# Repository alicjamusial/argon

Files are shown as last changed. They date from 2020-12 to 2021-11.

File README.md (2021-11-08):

# Argon & Benzene - SPI NOR Flash programmer & reader

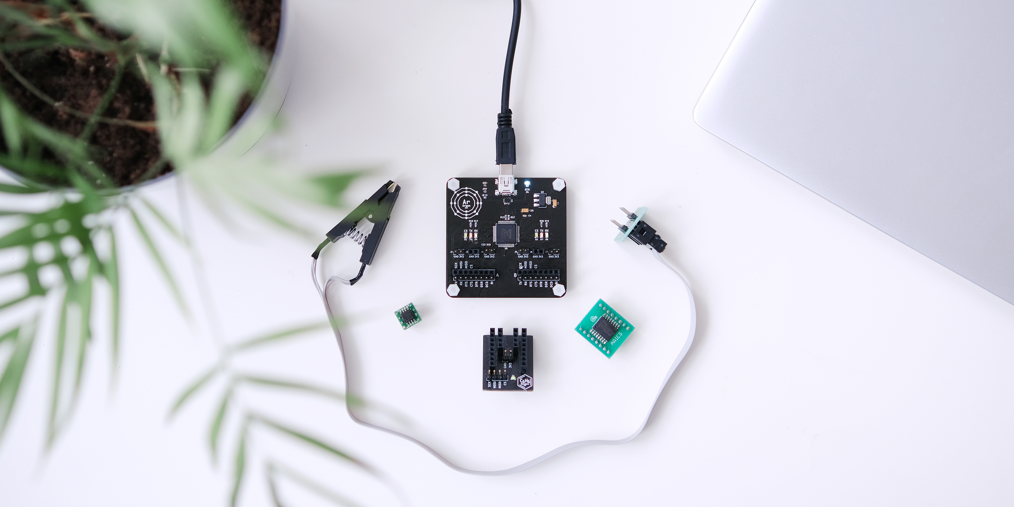
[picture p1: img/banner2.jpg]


### ◾ About the project

This project consists of two boards: **Argon** and **Benzene**.

 **Argon** is a SPI NOR flash programmer & reader. It's based on the FT2232H microcontroller (with two UARTs - A & B). The board has three LED indicators of data - on TX, RX and CS lines and some sockets to be able to plug in the logic analyzer. Version 1.0 of Argon is available [in the releases section](https://github.com/alicjamusial/argon/releases/tag/argon-1.0). 

<br>

 **Benzene** is a DIP-8/DIP-16 to Argon adapter. It includes mostly a few capacitors and resistors to allow SPI flash to run smoothly. There is also a 555 timer with LED indicator on CS line goldpins to attach the logic analyzer.
Version 1.0 of Benzene is available [in the releases section](https://github.com/alicjamusial/argon/releases/tag/benzene-1.0).

<br>
Argon works best with Benzene attached - they are designed to match each other (you can put two Benzene boards on top of the Argon). Argon can be also used separately as USB<->UART/FIFO/I2C/SPI converter (similar to FTDI Mini Module). 

Both boards were designed using [KiCad 5.1.6](https://kicad.org/).

### ◾ Software
Argon software is available in [this repository](https://github.com/alicjamusial/argon-driver).

### ◾ Known issues
**Argon 1.1**
- No known issues, but wasn't assembled yet.

**Benzene 1.0**
- Logo is too small and illegible (not very important, so won't be fixed by now)

**Project**
- KiCad libraries are a bit chaotic (not very important, so won't be fixed by now)

### ◾ Usage examples
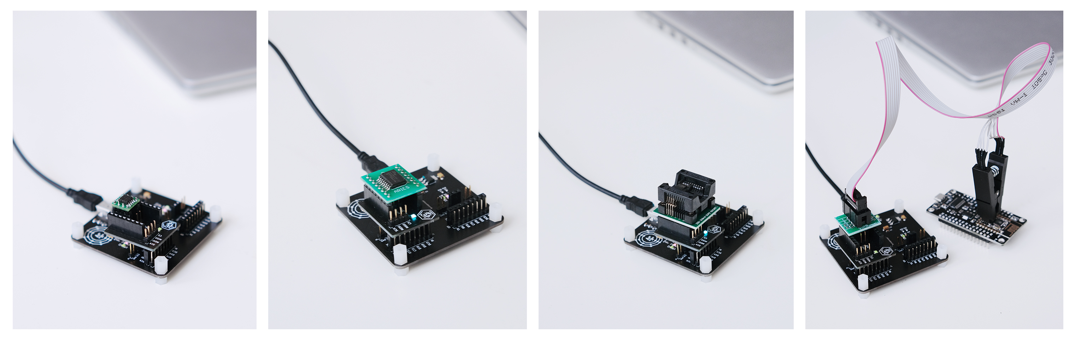
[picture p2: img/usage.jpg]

Argon is meant to be used as SPI NOR flash reader & writer with:
- Benzene & flash soldered to DIP-8/DIP-16 board adapter
- Benzene & flash inside DIP-8/DIP-16 adapter
- Benzene & clip with DIP-8/16 adapter to read or program flash placed on another board

It can be also used standalone as USB<->UART/FIFO/I2C/SPI converter (all FTDI Mini Module functionalities in the nicer and more readable form).

Note: all photos show Argon in version 1.0.

### ◾ Schematics and designs
All of them can be found [in the releases section](https://github.com/alicjamusial/argon/releases) as KiCad files, gerber files, pdf and svg format.

#### ▪️ Argon 1.1
schema
board
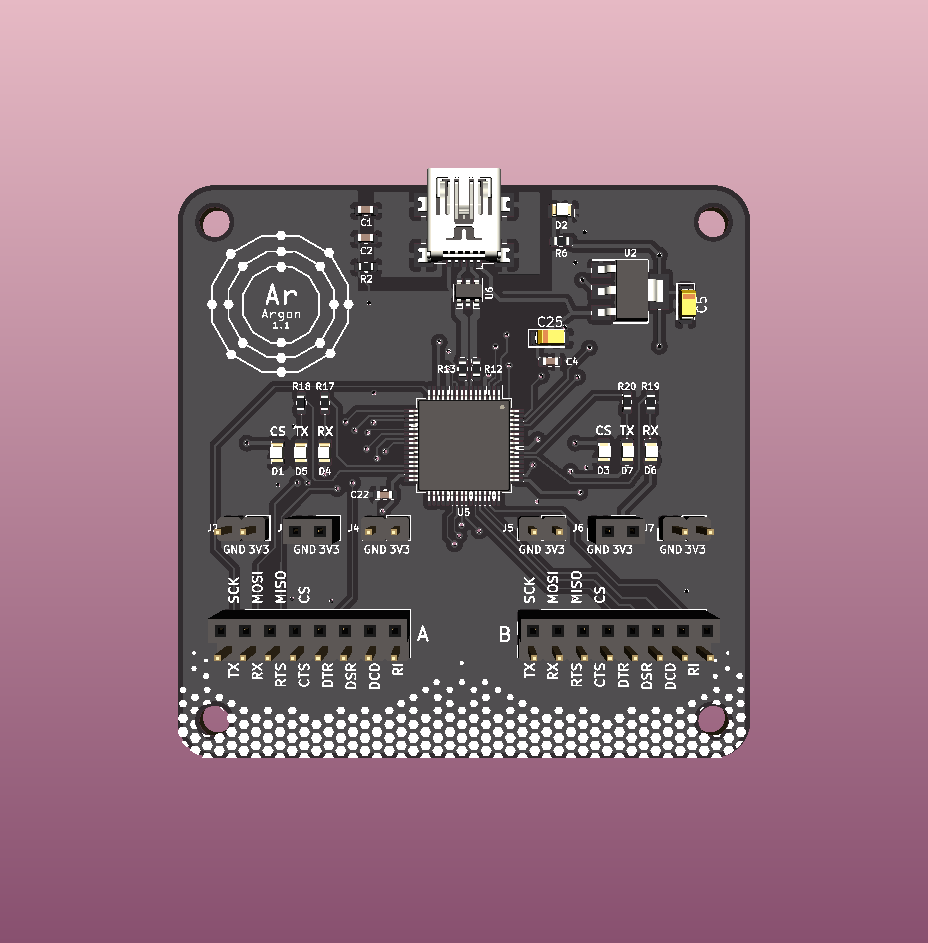
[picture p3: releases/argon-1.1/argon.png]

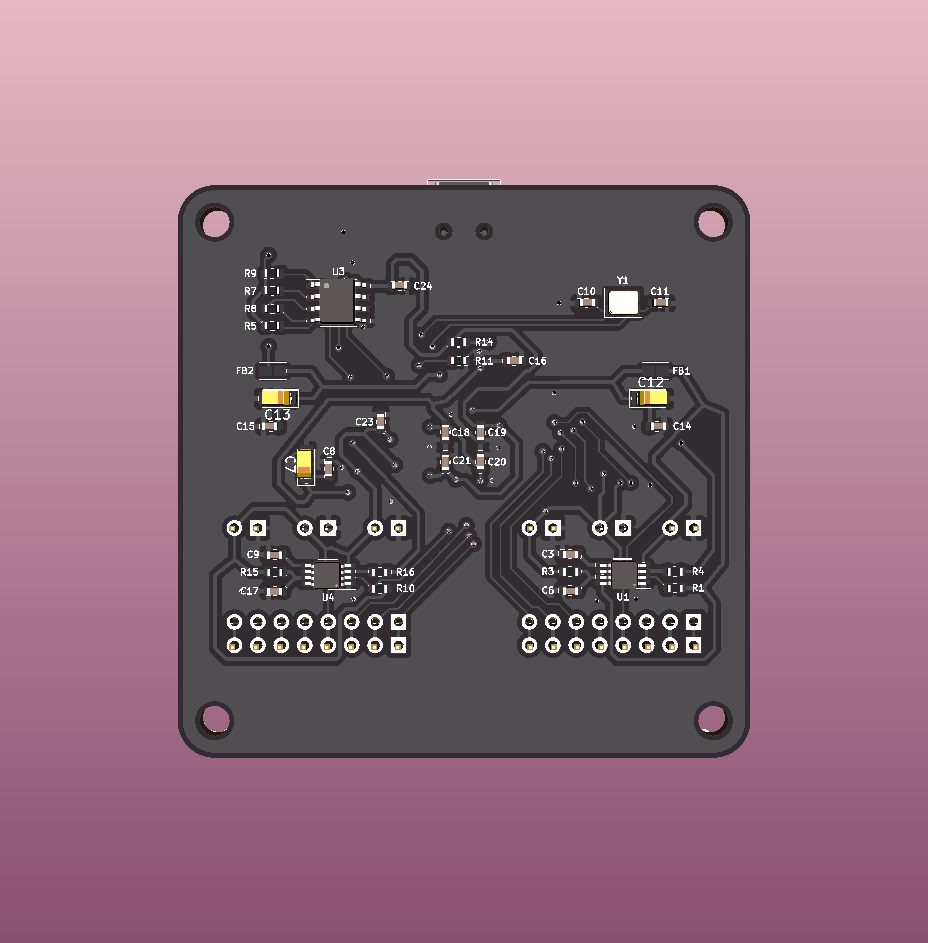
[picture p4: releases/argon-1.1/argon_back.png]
3d_back

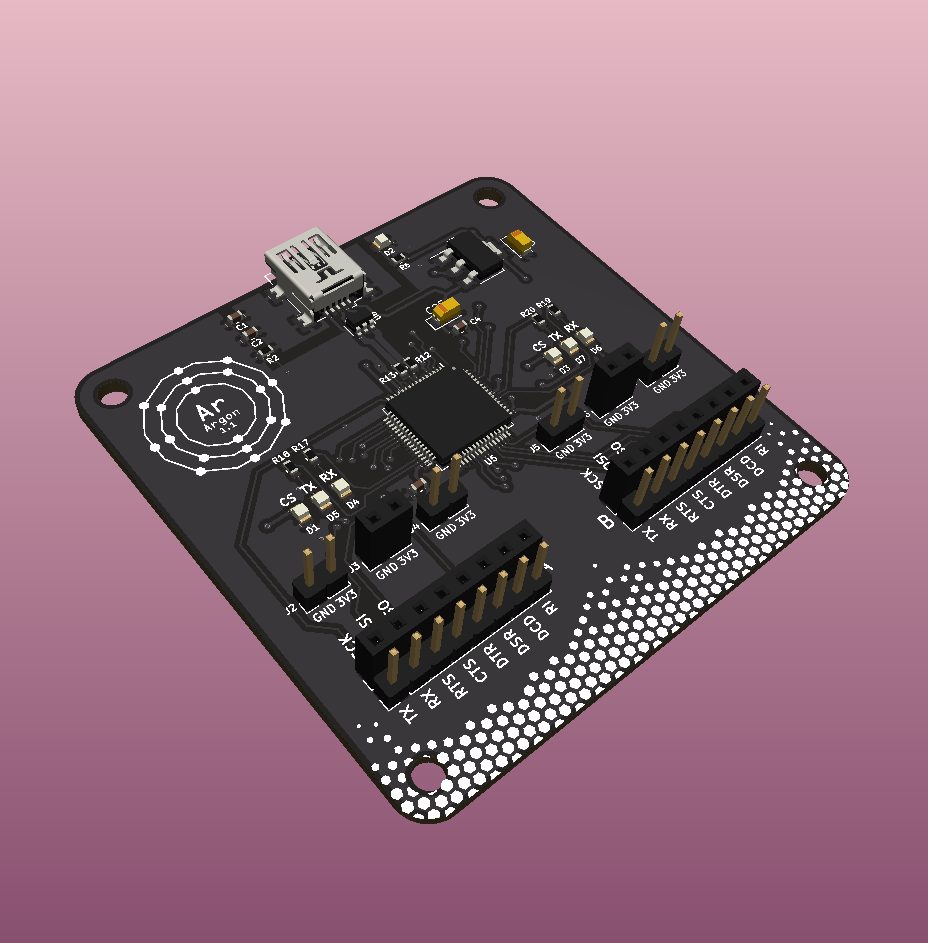
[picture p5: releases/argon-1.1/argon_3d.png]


#### ▪️ Benzene 1.0
schema
board
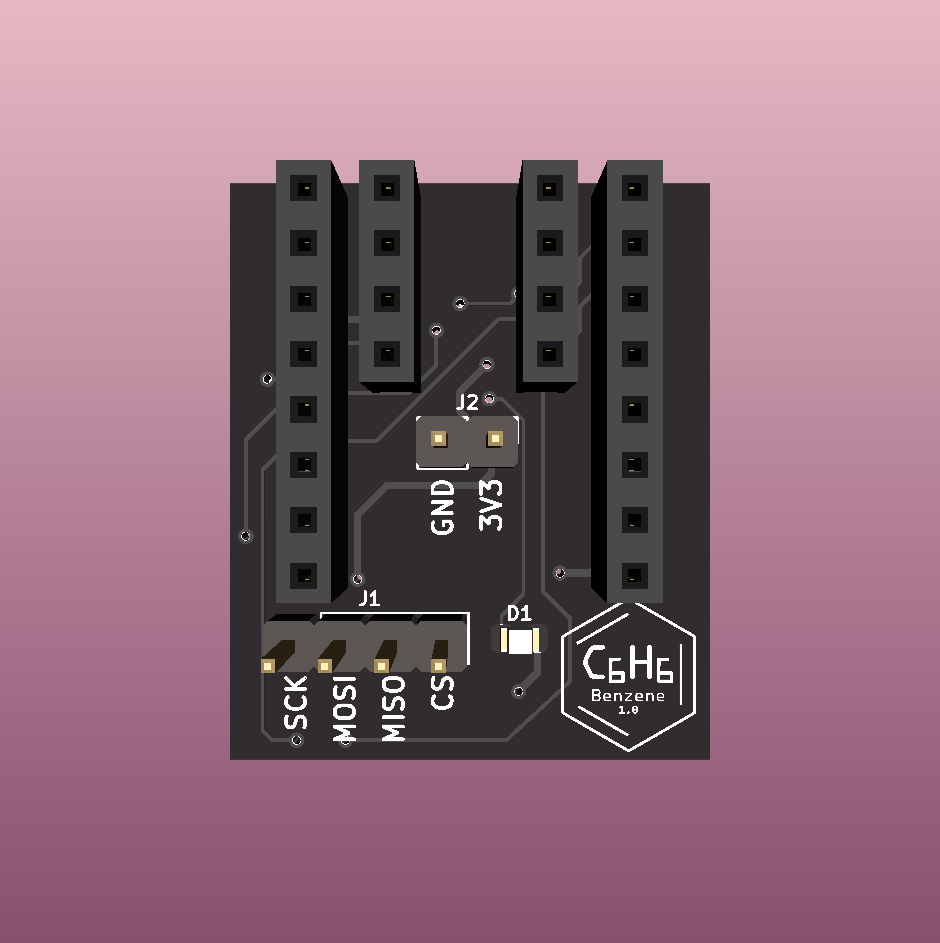
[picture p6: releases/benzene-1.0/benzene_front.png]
3d_front

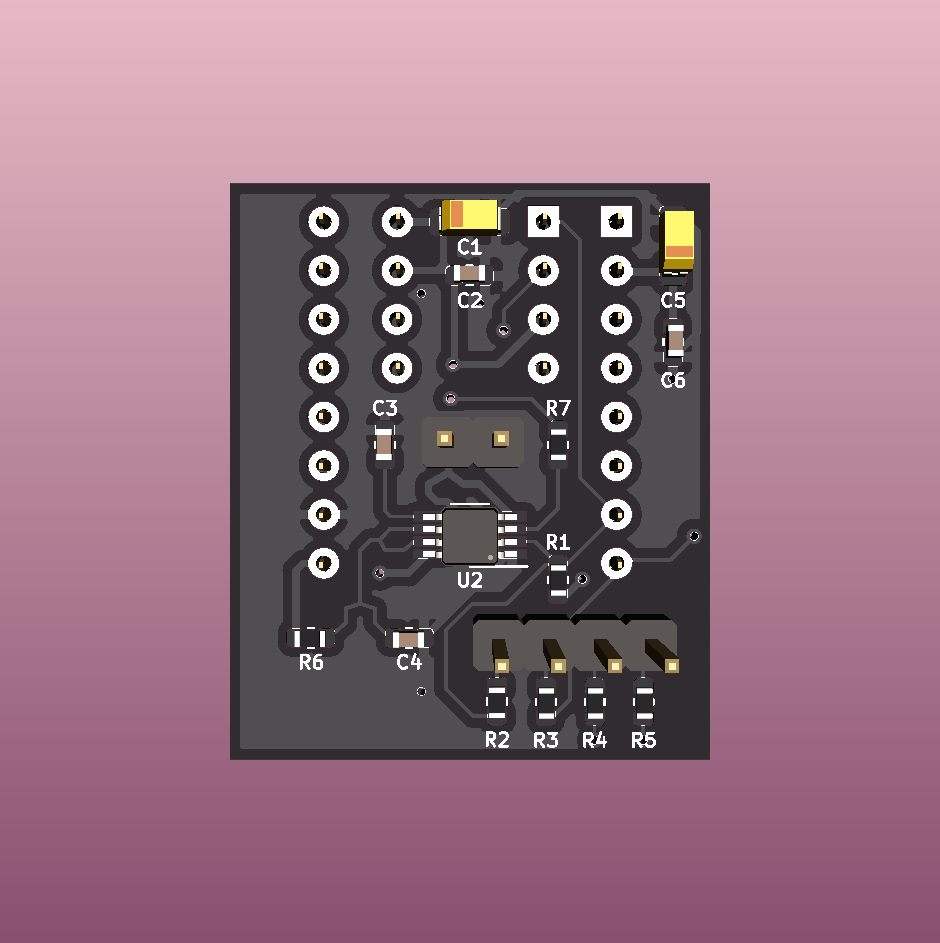
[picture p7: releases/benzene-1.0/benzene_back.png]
3d_back

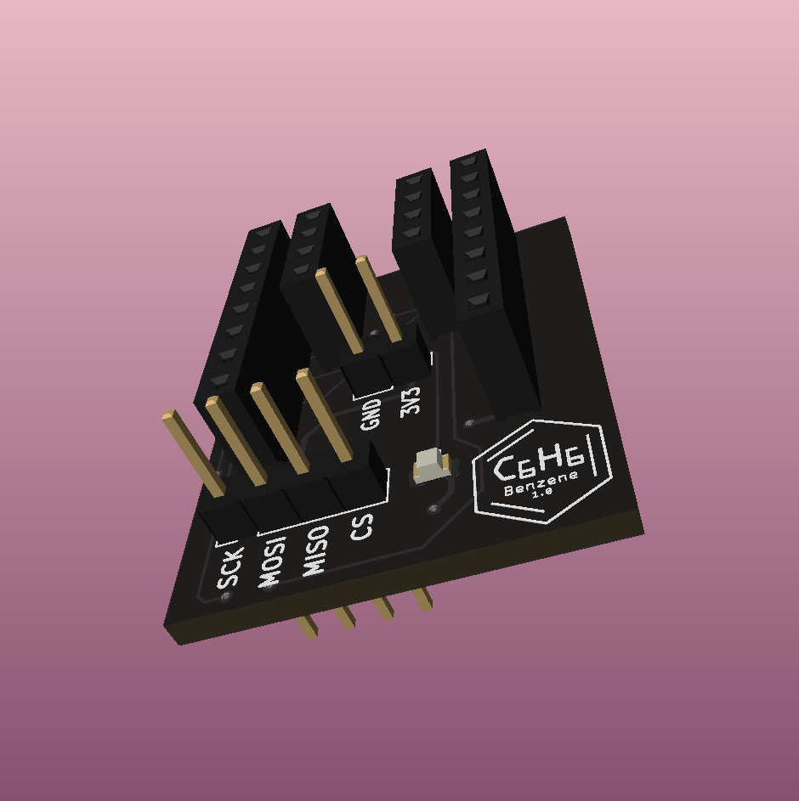
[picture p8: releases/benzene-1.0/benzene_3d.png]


### ◾ Other hints
When assembling your own Argon or Benzene please use LED's resistors calculated for your chosen colours.

### ◾ License
Argon and Benzene are available on Creative Commons Attribution Share Alike 4.0 International license (more in [license file](LICENSE.txt)). You are free to use it, modify it and produce as many of your own boards as you need :)

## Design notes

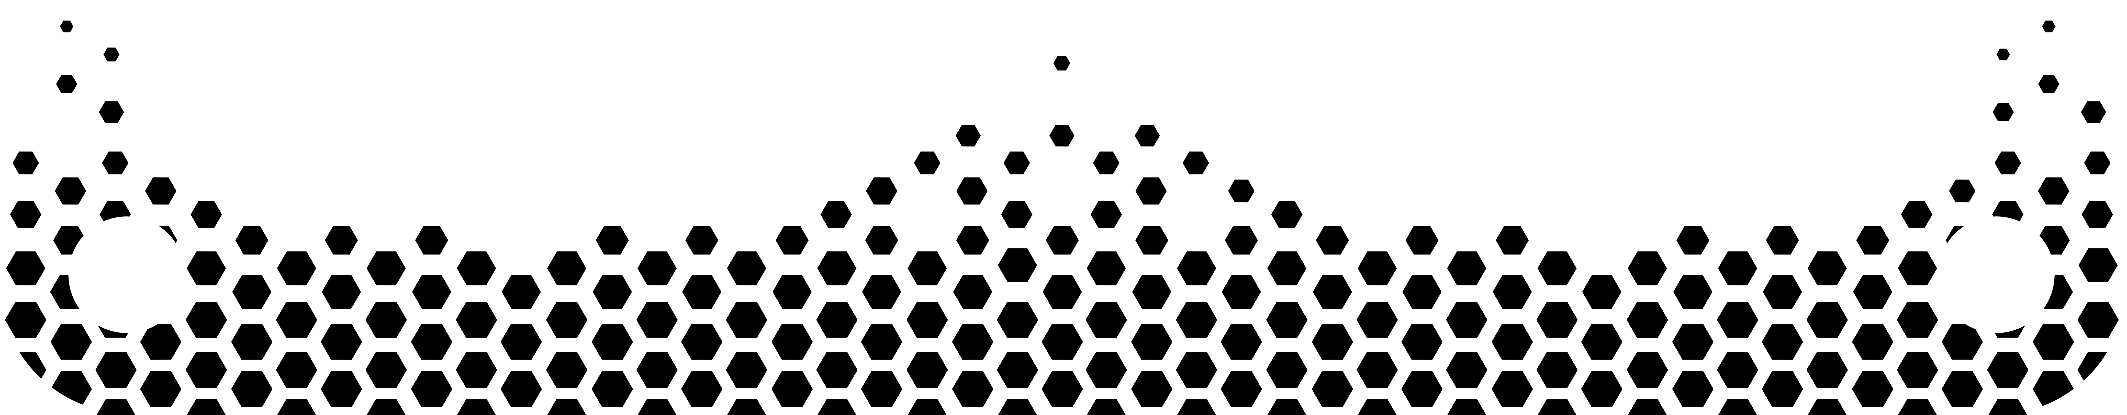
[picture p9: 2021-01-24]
img/pattern_argon.png

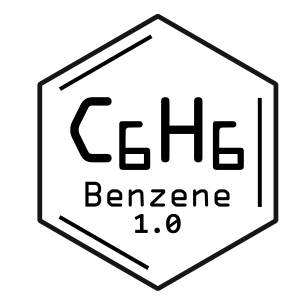
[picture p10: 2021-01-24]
benzene/benzene2.png

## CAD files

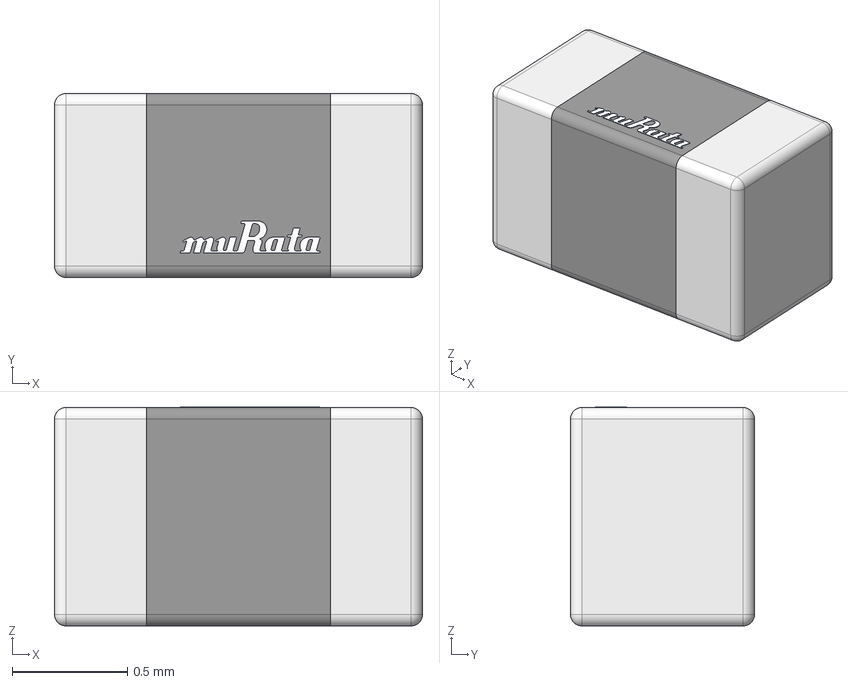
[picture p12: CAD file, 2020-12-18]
argon-libs/FBead_Murata_BLM18AG601SN1D/eec.models/Murata_-_BLM18AG601SN1D.step
1.60 x 0.8 x 0.952 mm
side x 2
Murata_

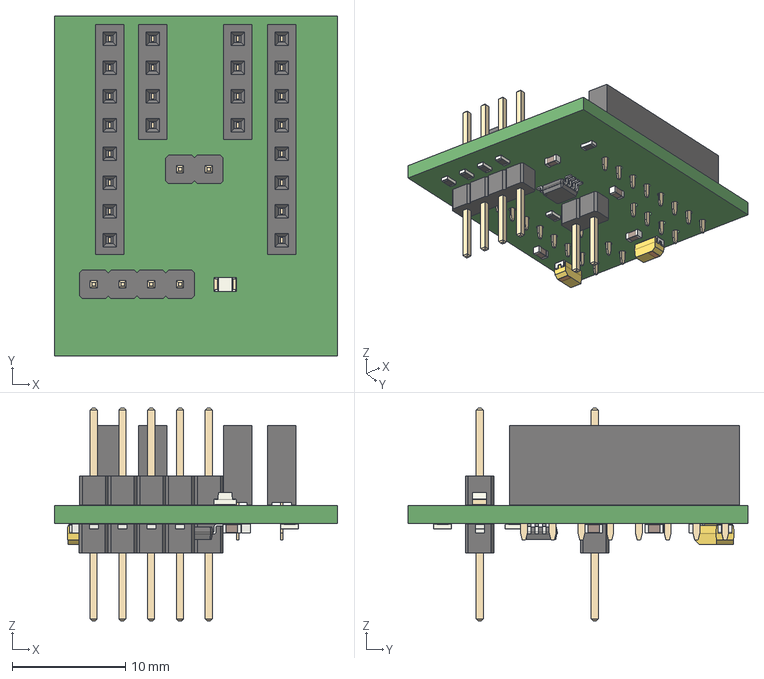
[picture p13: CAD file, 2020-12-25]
benzene/benzene.step
25.0 x 30.0 x 18.8 mm

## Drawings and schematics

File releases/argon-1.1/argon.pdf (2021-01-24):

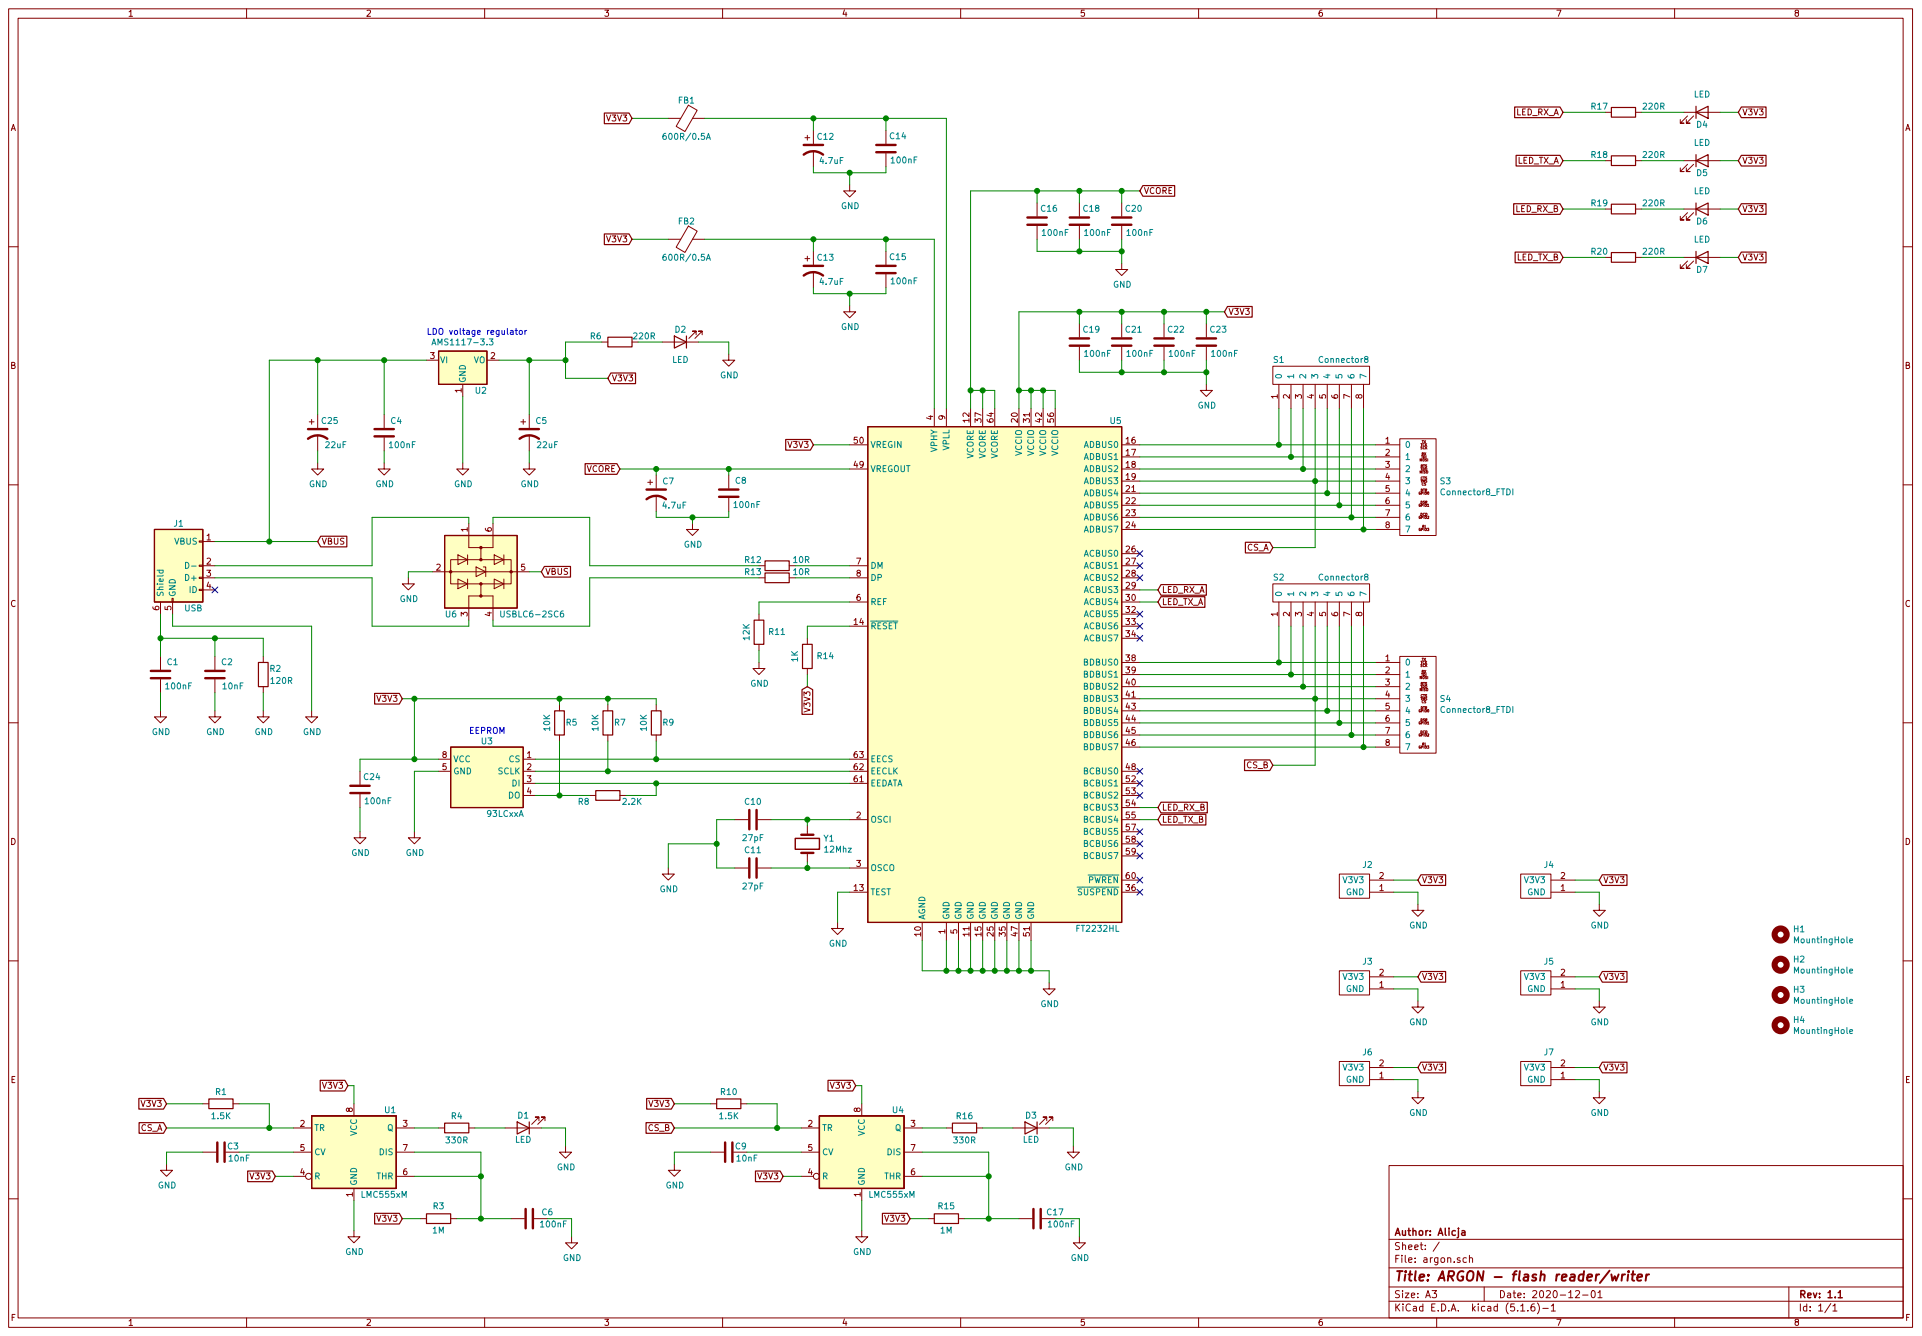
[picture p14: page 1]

1 AGND 10 GND 11 VCORE 12 TEST 13 RESET 14 GND 15 ADBUS0 16 ADBUS1 17 ADBUS2 18 ADBUS3 19 OSCI 2 VCCIO 20 ADBUS4 21 ADBUS5 22 ADBUS6 23 ADBUS7 24 GND 25 ACBUS0 26 ACBUS1 27 ACBUS2 28 ACBUS3 29 OSCO 3 ACBUS4 30 VCCIO 31 ACBUS5 32 ACBUS6 33 ACBUS7 34 GND 35 SUSPEND 36 VCORE 37 BDBUS0 38 BDBUS1 39 VPHY

4 BDBUS2 40 BDBUS3 41 VCCIO 42 BDBUS4 43 BDBUS5 44 BDBUS6 45 BDBUS7 46 GND 47 BCBUS0 48 VREGOUT 49 GND

5 VREGIN 50 GND 51 BCBUS1 52 BCBUS2 53 BCBUS3 54 BCBUS4 55 VCCIO 56 BCBUS5 57 BCBUS6 58 BCBUS7 59 REF 6 PWREN 60 EEDATA 61 EECLK 62 EECS 63 VCORE 64 DM 7 DP 8 VPLL

File: argon.sch Sheet: / Author: Alicja

Id: 1/1 Title: ARGON - flash reader/writer

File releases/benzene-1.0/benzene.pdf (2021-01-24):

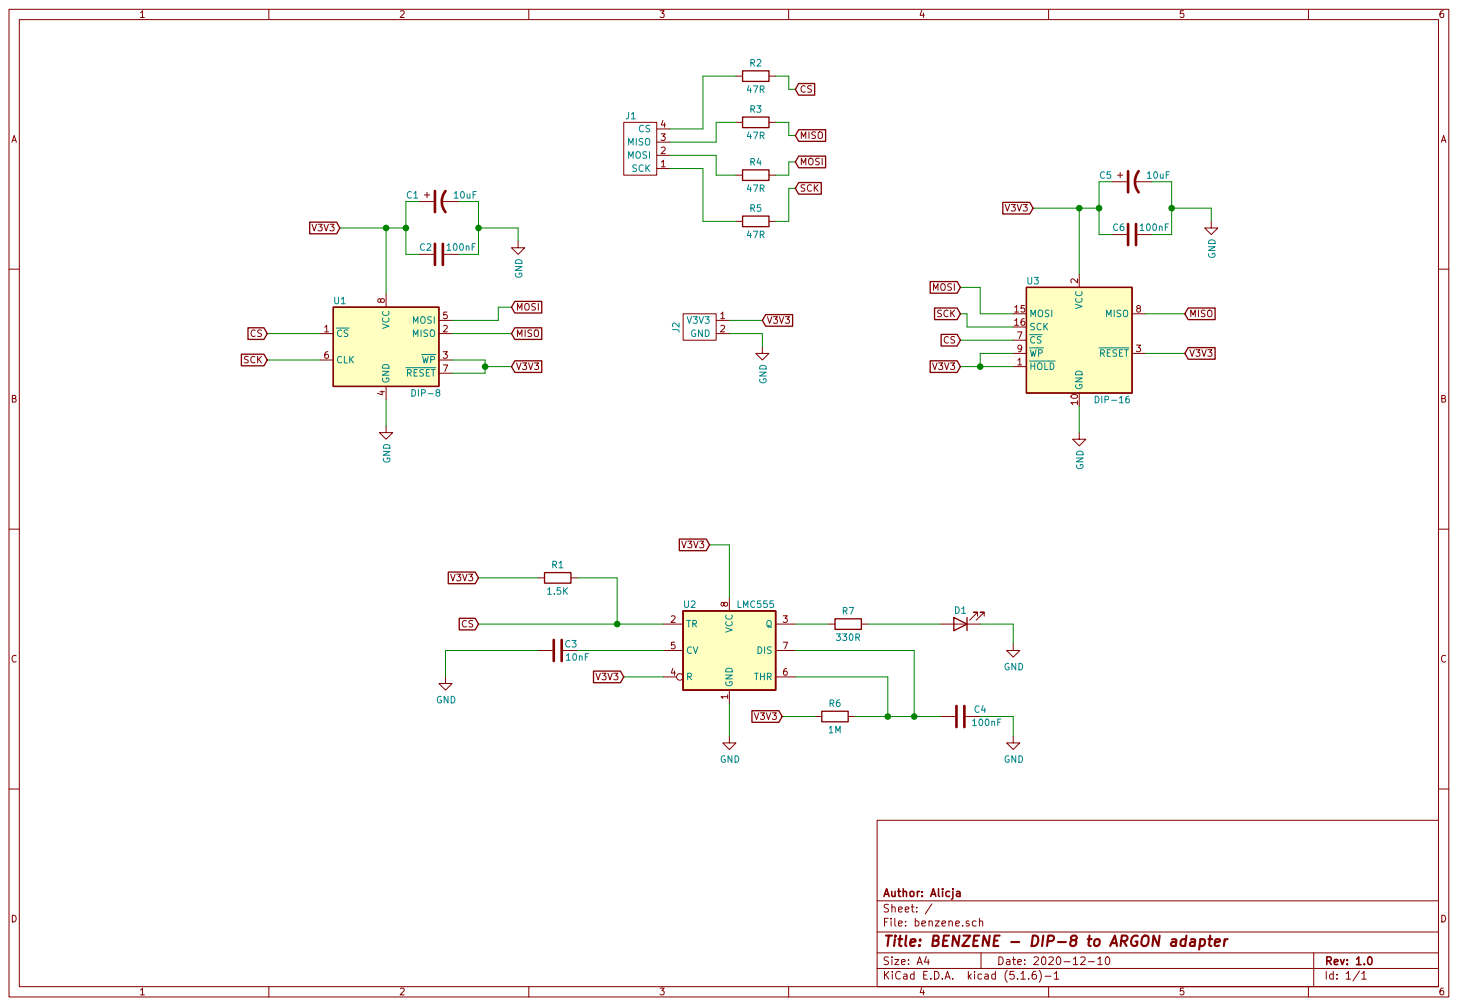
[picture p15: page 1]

2 RESET 3 CS 7 MISO 8 WP 9 U3 DIP-16 V3V3 1 GND J22 GND

4 MOSI 5 CLK 6 RESET 7 VCC

Id: 1/1 Title: BENZENE - DIP-8 to ARGON adapter File: benzene.sch Sheet: / Author: Alicja

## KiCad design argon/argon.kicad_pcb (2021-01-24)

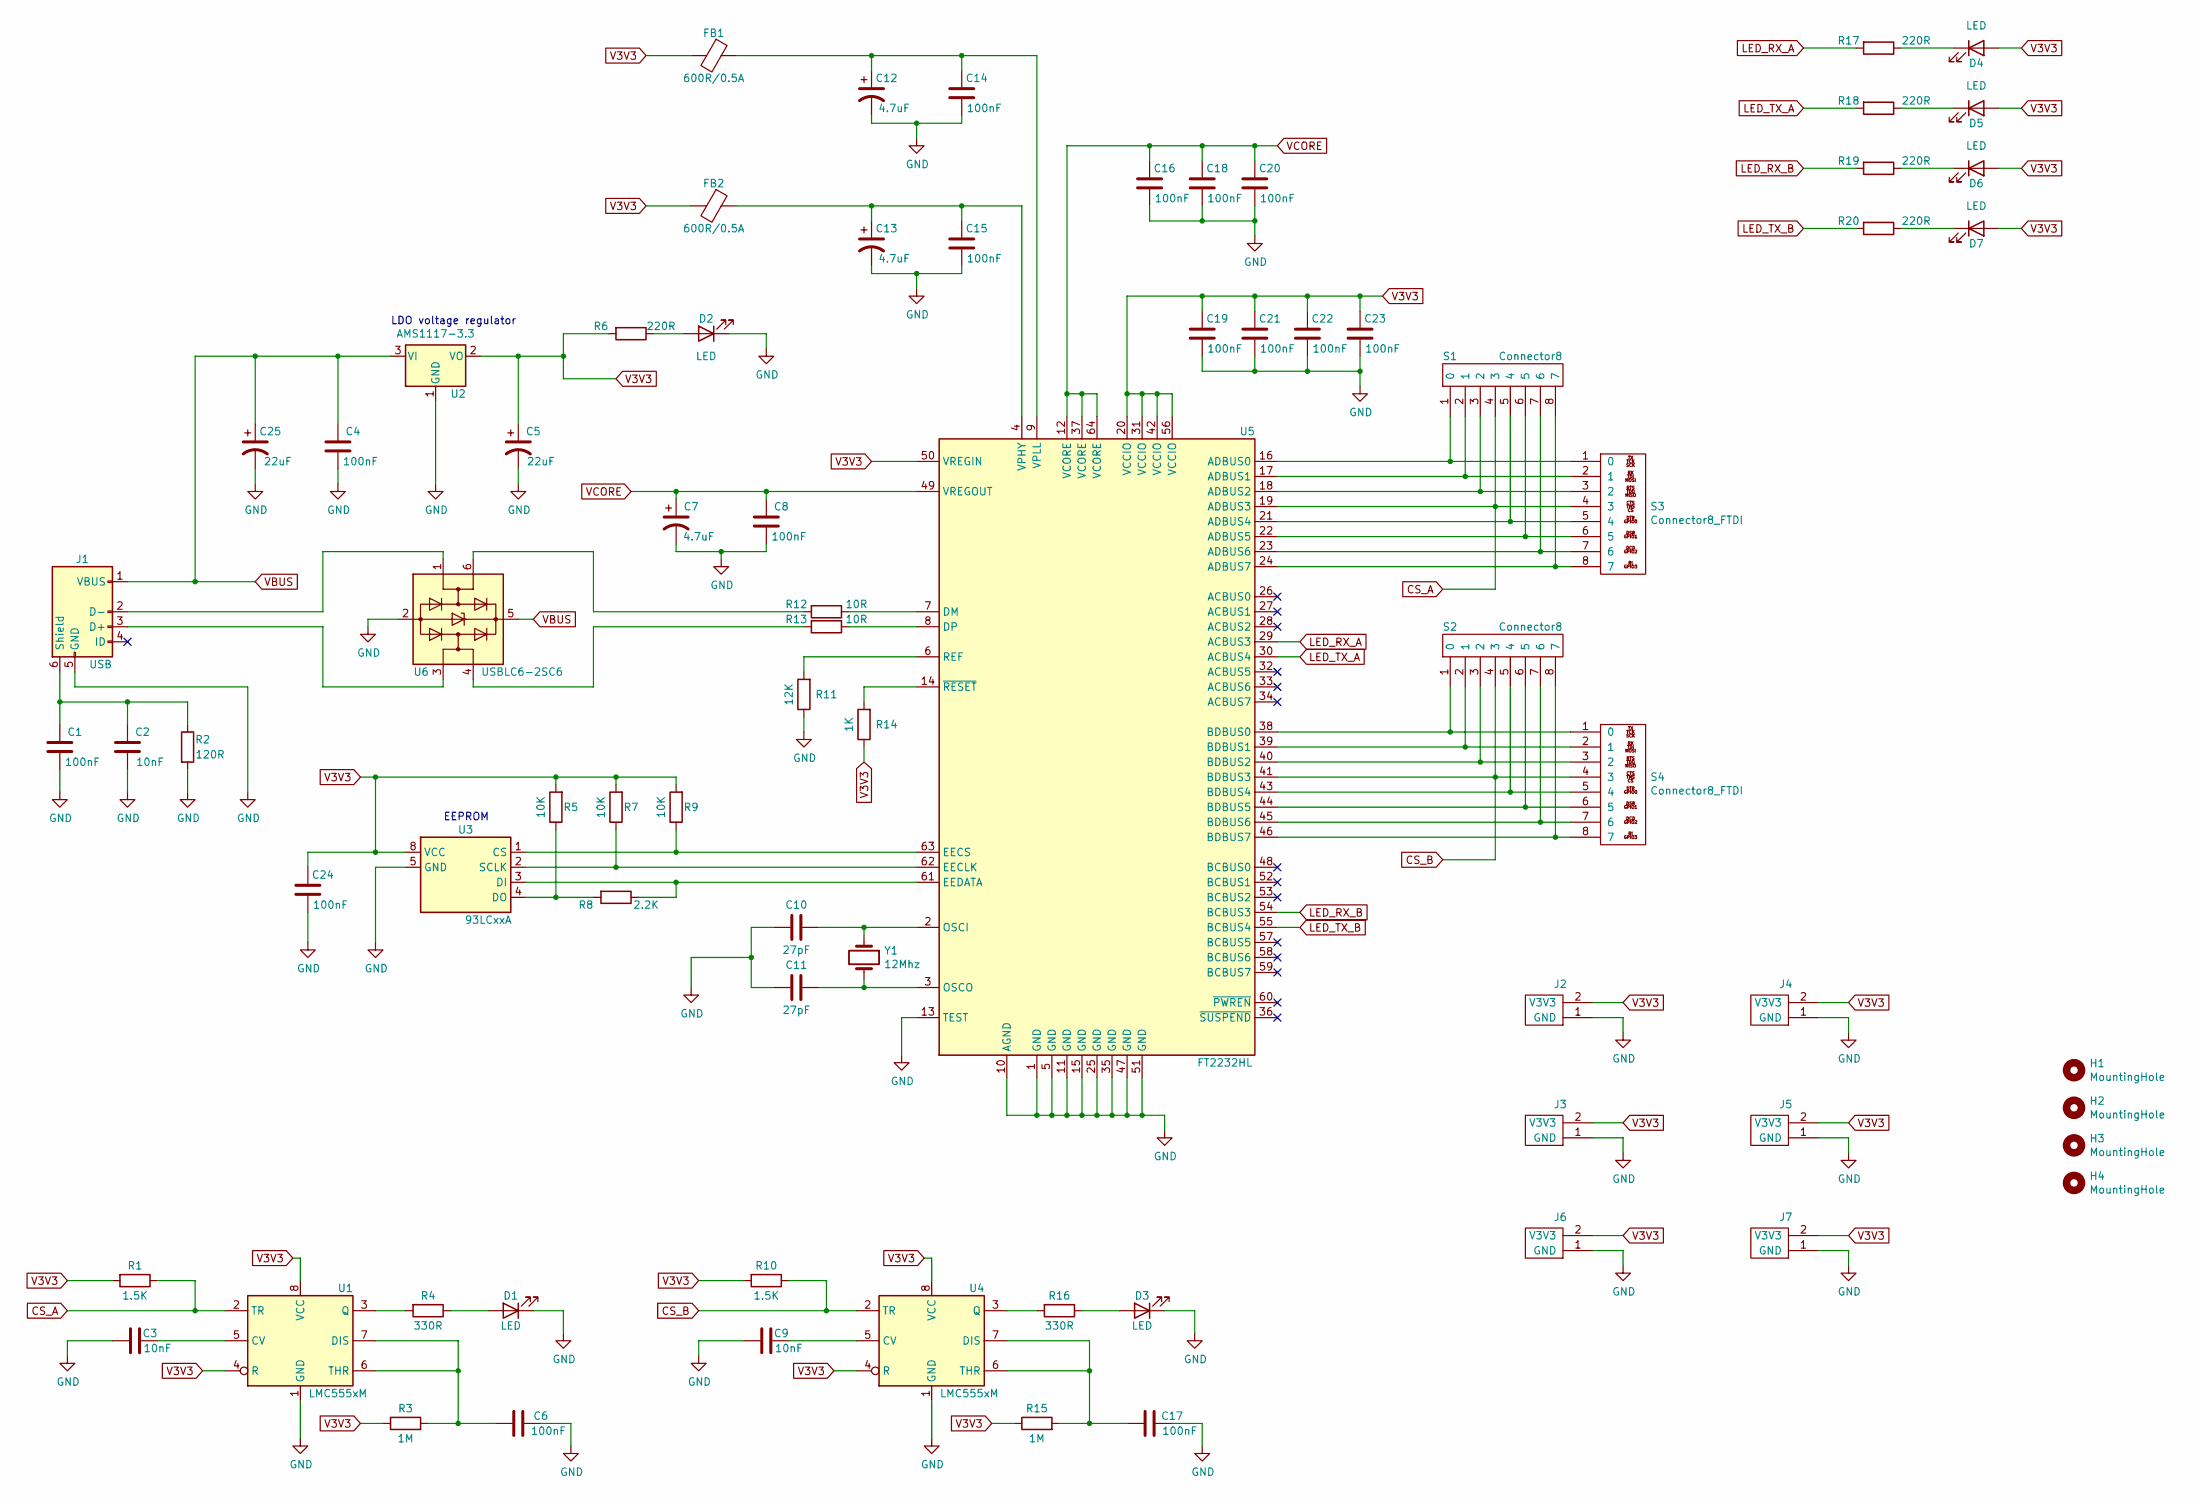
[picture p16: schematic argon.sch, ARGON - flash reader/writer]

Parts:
C1, C4, C6, C8, C14, C15, C16, C17, C18, C19, C20, C21, C22, C23, C24: 100nF; C_0603_1608Metric
C2, C3, C9: 10nF; C_0603_1608Metric
C5, C25: 22uF; CP_EIA-3216-18_Kemet-A
C7, C12, C13: 4.7uF; CP_EIA-3216-18_Kemet-A
C10, C11: 27pF; C_0603_1608Metric
D1, D2, D3, D4, D5, D6, D7: LED; LED_0805_2012Metric
FB1, FB2: 600R/0.5A; Murata-BLM18-0.15-t0.8-0-0-IPC_A
H1, H2, H3, H4: MountingHole; MountingHole_3.2mm_M3
J1: USB; USB_Mini-B_Wuerth_65100516121_Horizontal
J2, J3, J4, J5, J6, J7: V3V3-GND; PinHeader_1x02_P2.54mm_Vertical
R1, R10: 1.5K; R_0603_1608Metric
R2: 120R; R_0603_1608Metric
R3, R15: 1M; R_0603_1608Metric
R4, R16: 330R; R_0603_1608Metric
R5, R7, R9: 10K; R_0603_1608Metric
R6, R17, R18, R19, R20: 220R; R_0603_1608Metric
R8: 2.2K; R_0603_1608Metric
R11: 12K; R_0603_1608Metric
R12, R13: 10R; R_0603_1608Metric
R14: 1K; R_0603_1608Metric
S1, S2: Connector8; PinHeader_1x08_P2.54mm_Vertical
S3, S4: Connector8_FTDI; PinHeader_1x08_P2.54mm_Vertical
U1, U4: LMC555xM; VSSOP-8_3.0x3.0mm_P0.65mm
U2: AMS1117-3.3; SOT-223-3_TabPin2
U3: 93LCxxA; SOIC-8_3.9x4.9mm_P1.27mm
U5: FT2232HL; LQFP-64_10x10mm_P0.5mm
U6: USBLC6-2SC6; SOT-23-6
Y1: 12Mhz; Crystal_SMD_SeikoEpson_TSX3225-4Pin_3.2x2.5mm

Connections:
CS_A: R1.1, S1.4 (3), S3.4 (3), U1.2 (TR), U5.19 (ADBUS3)
CS_B: R10.1, S2.4 (3), S4.4 (3), U4.2 (TR), U5.41 (BDBUS3)
GND: C1.1, C2.1, C3.2, C4.2, C5.2, C6.2, C7.2, C8.1, C9.2, C10.2, C11.2, C12.2, C13.2, C14.1, C15.1, C16.1, C17.2, C18.1, C19.1, C20.1, C21.1, C22.1, C23.1, C24.1, C25.2, D1.1 (K), D2.1 (K), D3.1 (K), J1.5 (GND), J2.1 (GND), J3.1 (GND), J4.1 (GND), J5.1 (GND), J6.1 (GND), J7.1 (GND), R2.2, R11.1, U1.1 (GND), U2.1 (GND), U3.5 (GND), U4.1 (GND), U5.1 (GND), U5.5 (GND), U5.10 (AGND), U5.11 (GND), U5.13 (TEST), U5.15 (GND), U5.25 (GND), U5.35 (GND), U5.47 (GND), U5.51 (GND), U6.2 (GND)
LED_RX_A: R17.2, U5.29 (ACBUS3)
LED_RX_B: R19.2, U5.54 (BCBUS3)
LED_TX_A: R18.2, U5.30 (ACBUS4)
LED_TX_B: R20.2, U5.55 (BCBUS4)
unnamed: C1.2, C2.2, J1.6 (Shield), R2.1
unnamed: C3.1, U1.5 (CV)
unnamed: C6.1, R3.2, U1.6 (THR), U1.7 (DIS)
unnamed: C9.1, U4.5 (CV)
unnamed: C10.1, U5.2 (OSCI), Y1.1
unnamed: C11.1, U5.3 (OSCO), Y1.2
unnamed: C12.1, C14.2, FB1.1, U5.9 (VPLL)
unnamed: C13.1, C15.2, FB2.1, U5.4 (VPHY)
unnamed: C17.1, R15.2, U4.6 (THR), U4.7 (DIS)
unnamed: D1.2 (A), R4.1
unnamed: D2.2 (A), R6.1
unnamed: D3.2 (A), R16.1
unnamed: D4.1 (K), R17.1
unnamed: D5.1 (K), R18.1
unnamed: D6.1 (K), R19.1
unnamed: D7.1 (K), R20.1
unnamed: J1.2 (D-), U6.1 (I/O1)
unnamed: J1.3 (D+), U6.3 (I/O2)
unnamed: R4.2, U1.3 (Q)
unnamed: R5.1, R8.2, U3.4 (DO)
unnamed: R7.1, U3.2 (SCLK), U5.62 (EECLK)
unnamed: R8.1, U3.3 (DI), U5.61 (EEDATA)
unnamed: R9.1, U3.1 (CS), U5.63 (EECS)
unnamed: R11.2, U5.6 (REF)
unnamed: R12.1, U5.7 (DM)
unnamed: R12.2, U6.6 (I/O1)
unnamed: R13.1, U5.8 (DP)
unnamed: R13.2, U6.4 (I/O2)
unnamed: R14.2, U5.14 (~RESET)
unnamed: R16.2, U4.3 (Q)
unnamed: S1.1 (0), S3.1 (0), U5.16 (ADBUS0)
unnamed: S1.2 (1), S3.2 (1), U5.17 (ADBUS1)
unnamed: S1.3 (2), S3.3 (2), U5.18 (ADBUS2)
unnamed: S1.5 (4), S3.5 (4), U5.21 (ADBUS4)
unnamed: S1.6 (5), S3.6 (5), U5.22 (ADBUS5)
unnamed: S1.7 (6), S3.7 (6), U5.23 (ADBUS6)
unnamed: S1.8 (7), S3.8 (7), U5.24 (ADBUS7)
unnamed: S2.1 (0), S4.1 (0), U5.38 (BDBUS0)
unnamed: S2.2 (1), S4.2 (1), U5.39 (BDBUS1)
unnamed: S2.3 (2), S4.3 (2), U5.40 (BDBUS2)
unnamed: S2.5 (4), S4.5 (4), U5.43 (BDBUS4)
unnamed: S2.6 (5), S4.6 (5), U5.44 (BDBUS5)
unnamed: S2.7 (6), S4.7 (6), U5.45 (BDBUS6)
unnamed: S2.8 (7), S4.8 (7), U5.46 (BDBUS7)
V3V3: C5.1, C19.2, C21.2, C22.2, C23.2, C24.2, D4.2 (A), D5.2 (A), D6.2 (A), D7.2 (A), FB1.2, FB2.2, J2.2 (V3V3), J3.2 (V3V3), J4.2 (V3V3), J5.2 (V3V3), J6.2 (V3V3), J7.2 (V3V3), R1.2, R3.1, R5.2, R6.2, R7.2, R9.2, R10.2, R14.1, R15.1, U1.4 (R), U1.8 (VCC), U2.2 (VO), U3.8 (VCC), U4.4 (R), U4.8 (VCC), U5.20 (VCCIO), U5.31 (VCCIO), U5.42 (VCCIO), U5.50 (VREGIN), U5.56 (VCCIO)
VBUS: C4.1, C25.1, J1.1 (VBUS), U2.3 (VI), U6.5 (VBUS)
VCORE: C7.1, C8.2, C16.2, C18.2, C20.2, U5.12 (VCORE), U5.37 (VCORE), U5.49 (VREGOUT), U5.64 (VCORE)

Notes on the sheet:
LDO voltage regulator
EEPROM

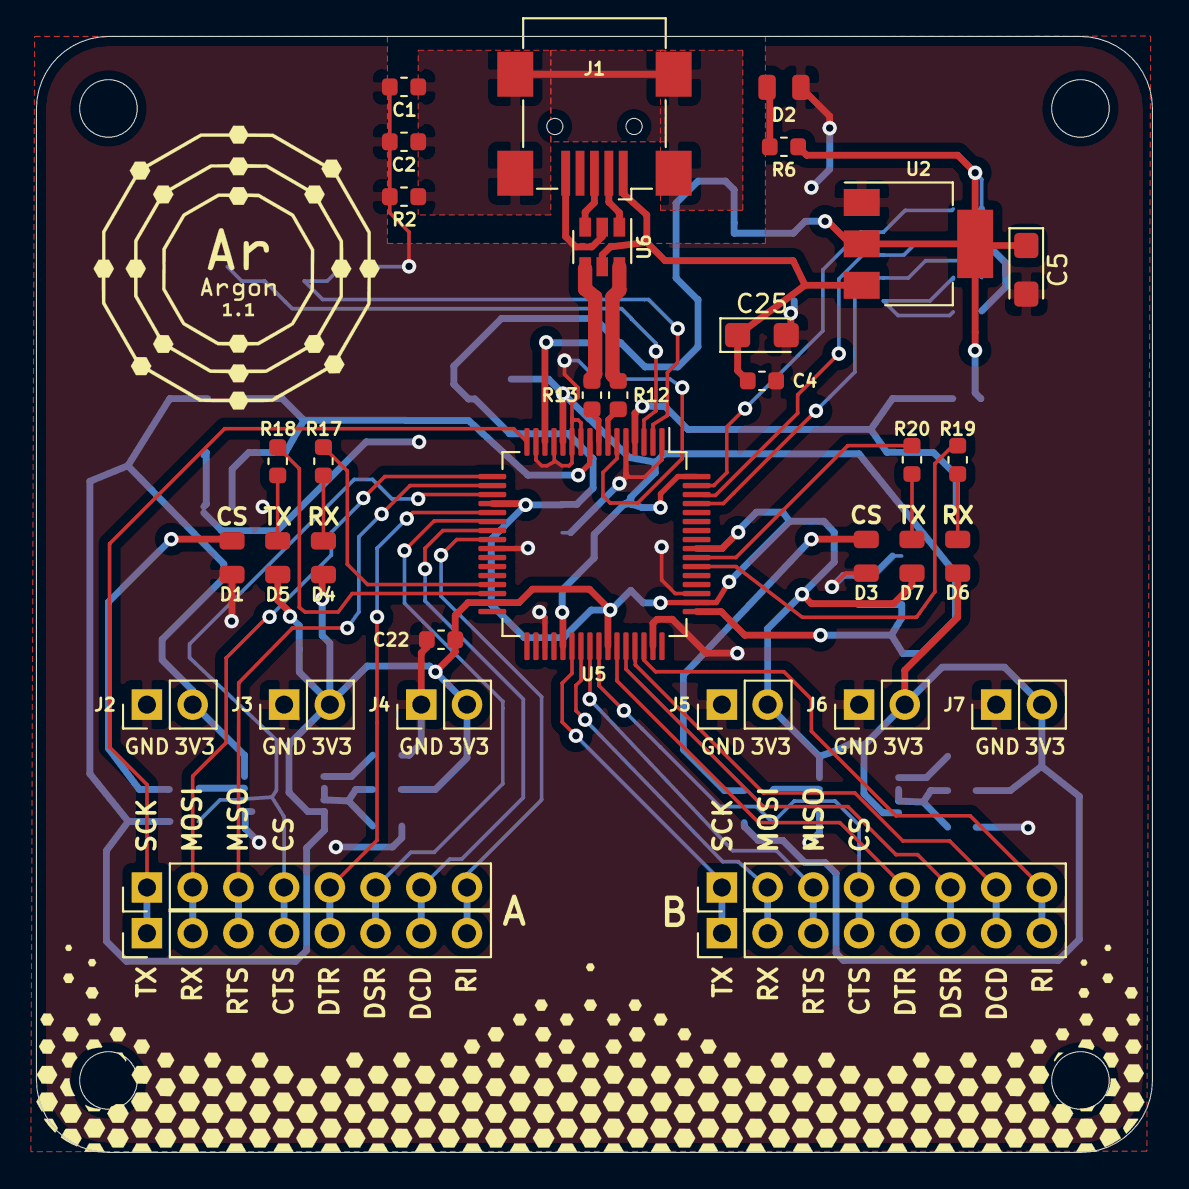
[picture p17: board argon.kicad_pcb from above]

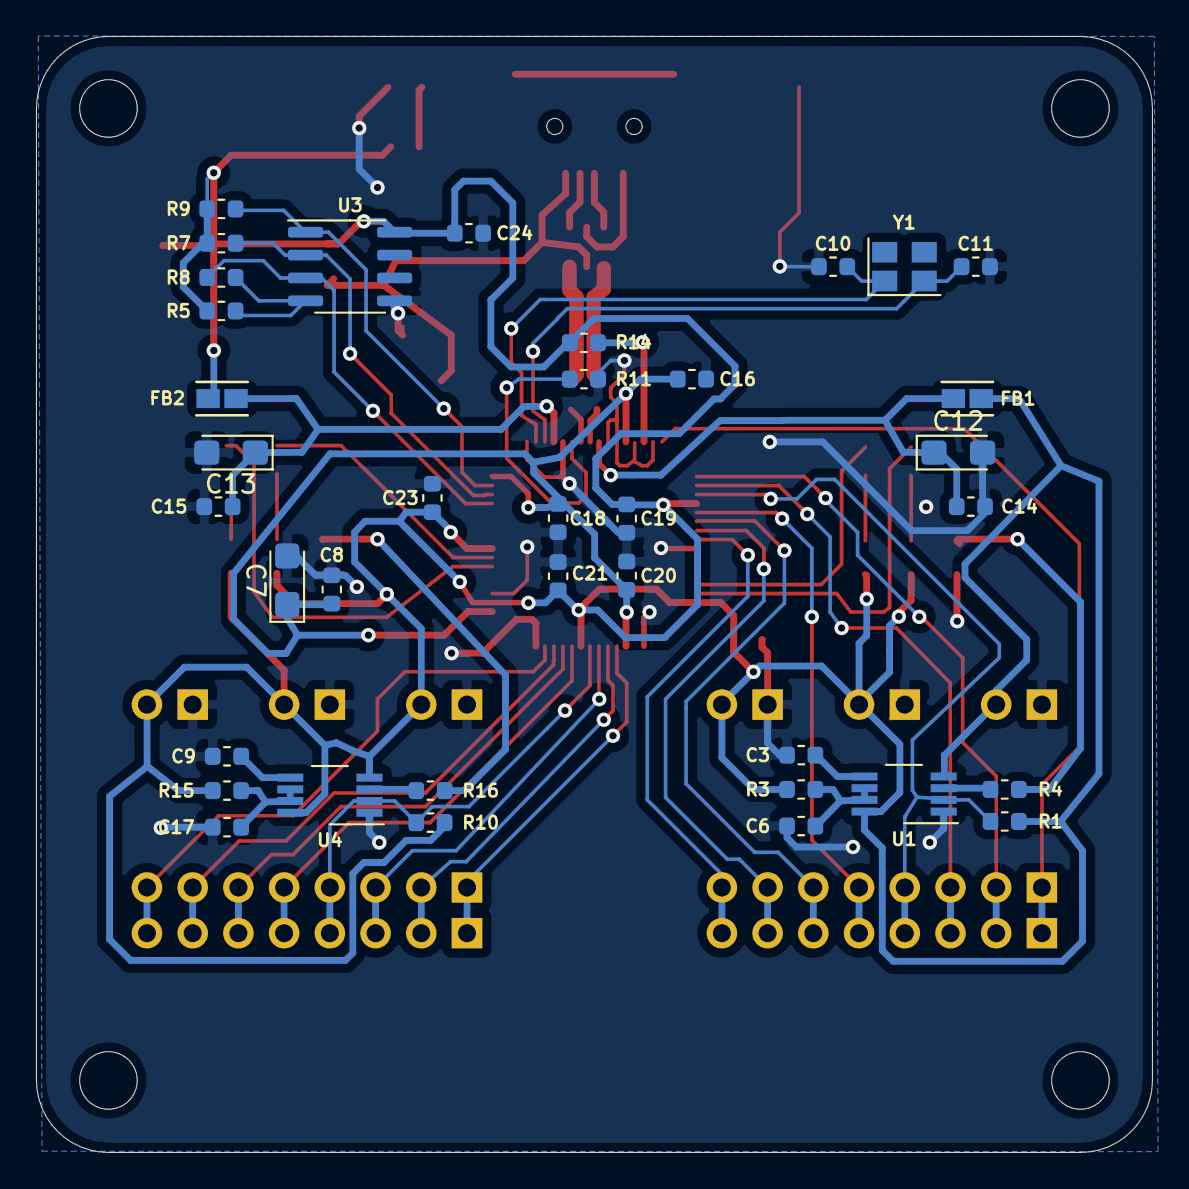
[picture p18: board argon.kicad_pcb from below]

Board: 2 copper layers, 62.0 x 62.0 mm, 76 parts (37 on the bottom side), 54 nets.

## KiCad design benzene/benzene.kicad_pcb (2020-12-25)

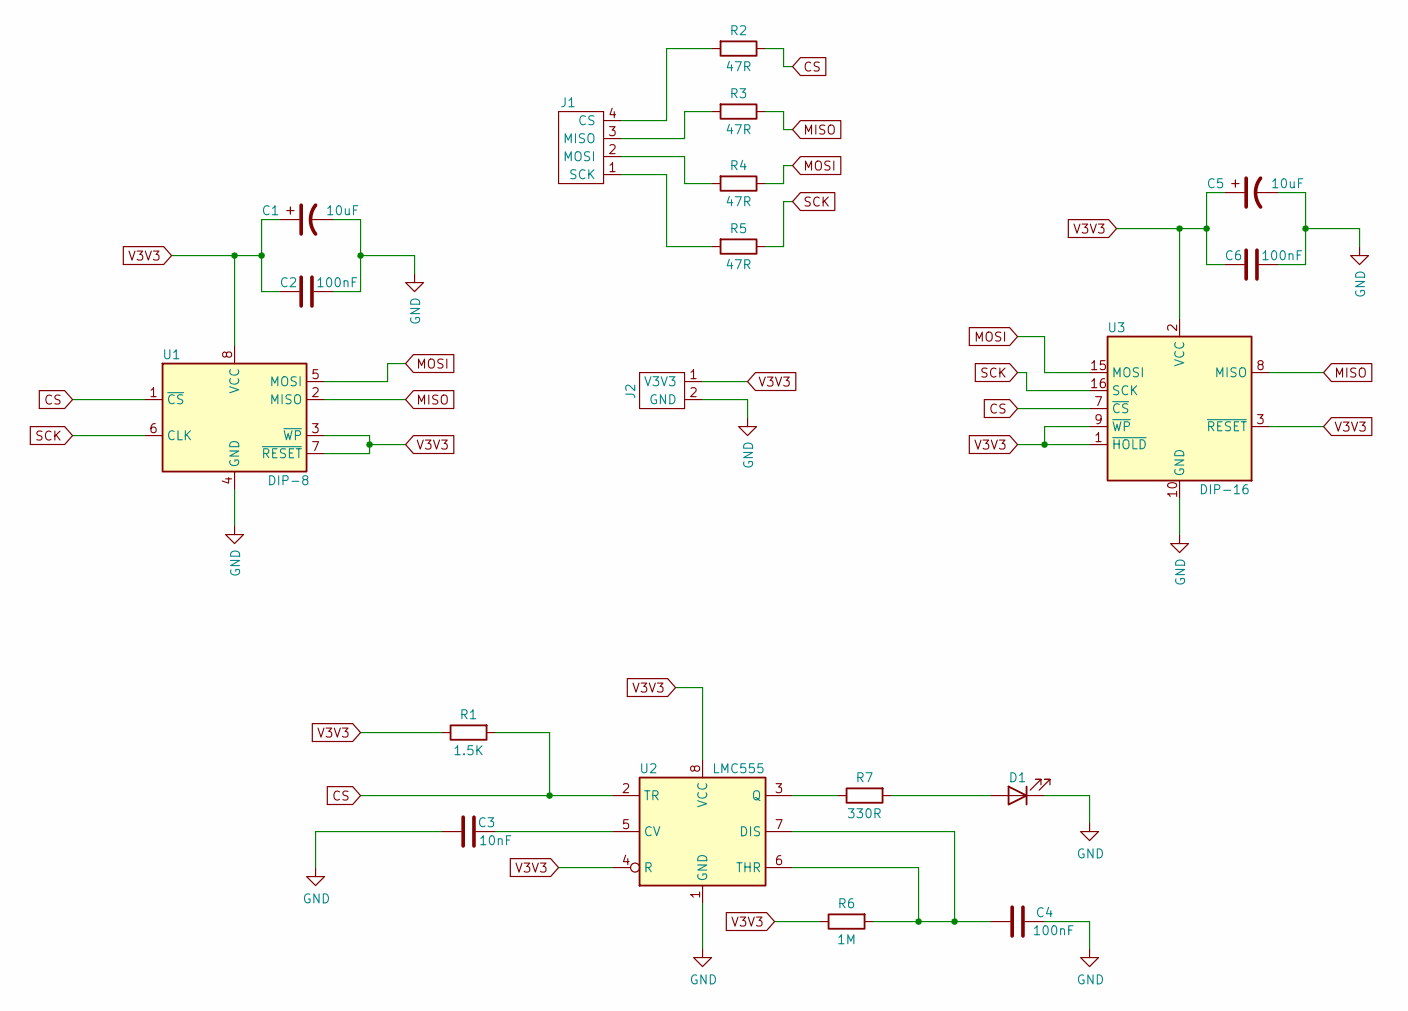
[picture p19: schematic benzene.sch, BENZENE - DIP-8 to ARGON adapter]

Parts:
C1, C5: 10uF; CP_EIA-3216-18_Kemet-A
C2, C4, C6: 100nF; C_0603_1608Metric
C3: 10nF; C_0603_1608Metric
D1: LED; LED_0805_2012Metric
J1: Conn2; PinHeader_1x04_P2.54mm_Vertical
J2: Conn1; PinHeader_1x02_P2.54mm_Vertical
R1: 1.5K; R_0603_1608Metric
R2, R3, R4, R5: 47R; R_0603_1608Metric
R6: 1M; R_0603_1608Metric
R7: 330R; R_0603_1608Metric
U1: DIP-8; DIP-8_W7.62mm_Socket_wihtout_lines
U2: LMC555; VSSOP-8_3.0x3.0mm_P0.65mm
U3: DIP-16; DIP-16_W15.24mm_without_lines

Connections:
CS: R1.2, R2.1, U1.1 (~CS), U2.2 (TR), U3.7 (~CS)
GND: C1.2, C2.1, C3.1, C4.2, C5.2, C6.1, D1.1 (K), J2.2 (GND), U1.4 (GND), U2.1 (GND), U3.10 (GND)
MISO: R3.1, U1.2 (MISO), U3.8 (MISO)
MOSI: R4.1, U1.5 (MOSI), U3.15 (MOSI)
unnamed: C3.2, U2.5 (CV)
unnamed: C4.1, R6.2, U2.6 (THR), U2.7 (DIS)
unnamed: D1.2 (A), R7.2
unnamed: J1.1 (SCK), R5.2
unnamed: J1.2 (MOSI), R4.2
unnamed: J1.3 (MISO), R3.2
unnamed: J1.4 (CS), R2.2
unnamed: R7.1, U2.3 (Q)
SCK: R5.1, U1.6 (CLK), U3.16 (SCK)
V3V3: C1.1, C2.2, C5.1, C6.2, J2.1 (V3V3), R1.1, R6.1, U1.3 (~WP), U1.7 (~RESET), U1.8 (VCC), U2.4 (R), U2.8 (VCC), U3.1 (~HOLD), U3.2 (VCC), U3.3 (~RESET), U3.9 (~WP)

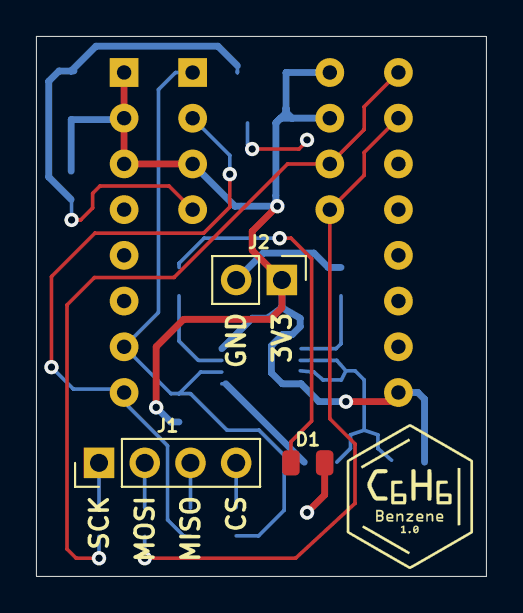
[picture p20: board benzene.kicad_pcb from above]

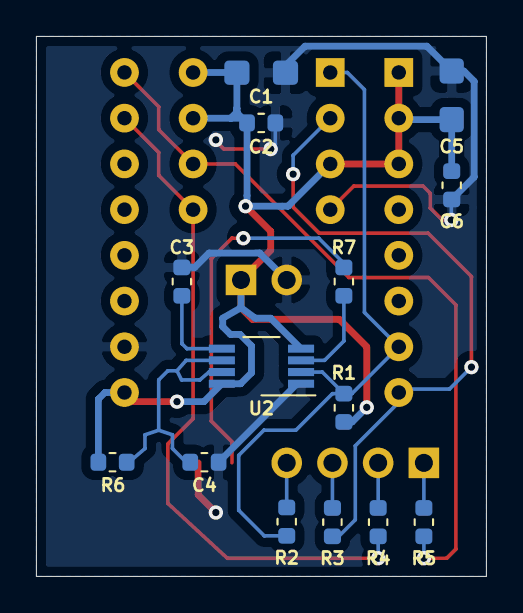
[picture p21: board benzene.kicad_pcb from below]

Board: 2 copper layers, 25.0 x 30.0 mm, 19 parts (14 on the bottom side), 14 nets.

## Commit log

2020-12-01 Repo init
    [argon.kicad_pcb, argon.sch]
2020-12-06 Add EEPROM & fix libs
    [argon.sch]
2020-12-06 Place 555
    [argon.sch]
2020-12-08 Add 555
    [argon.sch]
2020-12-08 Add LDO
    [argon.sch]
2020-12-11 Add benzene-8
    [benzene.kicad_pcb, benzene.sch]
2020-12-11 Add 555 to benzene
    [benzene.sch]
2020-12-11 Benzene & 555 - redraw to two schemas
    [benzene.sch]
2020-12-11 Benzene footprints
    [benzene.kicad_pcb, benzene.sch]
2020-12-12 Benzene - PCB, part 1
    [benzene.kicad_pcb, benzene.sch]
2020-12-12 Benzene - part 2 PCB
    [benzene.kicad_pcb]
2020-12-12 Benzene - verson with logo and centered 2 pins
    [benzene.kicad_pcb]
2020-12-12 Add logos & author
    [benzene.kicad_pcb]
2020-12-12 Benzene prealpha
    [benzene.kicad_pcb]
2020-12-13 25x15 - part1
    [benzene.kicad_pcb]
2020-12-13 Benzene refactored
    [benzene.kicad_pcb, benzene.sch]
2020-12-13 Benzene 16
    [benzene-16.kicad_pcb, benzene-16.sch]
2020-12-13 Chaotic evil - argon, benzen, some random freecad
    [argon.kicad_pcb, argon.sch, benzene.step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]
2020-12-14 Argon USB & custom footprint for DIP-16
    [argon.kicad_pcb, argon.sch, benzene-16.kicad_pcb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]
2020-12-18 Aegon USB and power
    [argon.kicad_pcb, argon.sch, benzene-16.kicad_pcb]
2020-12-18 More voltages
    [argon.sch]
2020-12-18 Leds & structure
    [argon.sch]
2020-12-18 Fix bugs
    [argon.sch]
2020-12-18 Final schematic
    [argon.sch]
2020-12-18 Add FBs and start positioning buses on PCB
    [Murata_-_BLM18AG601SN1D.step, argon.kicad_pcb, argon.sch]
2020-12-19 Clear folders
    [zlozenie1.FCStd]
2020-12-19 PCB - part 1
    [argon.kicad_pcb, argon.sch]
2020-12-19 Argon PCB - part 2 + logo
    [argon.kicad_pcb, argon.sch, benzene-16.sch]
2020-12-19 Change some capacitors to tantals
    [argon.kicad_pcb, argon.sch]
2020-12-19 PCB 6x6cm
    [argon.kicad_pcb]
2020-12-19 PCB - chaotic
    [argon.kicad_pcb, argon.sch]
2020-12-19 10.16mm between sockets on argon & benzene
    [argon.kicad_pcb, benzene-16.kicad_pcb]
2020-12-20 Argon PCB
    [argon.kicad_pcb]
2020-12-20 Piotrek's review
    [argon.sch]
2020-12-22 Argon & beznen compatible
    [argon.kicad_pcb, benzene-16.kicad_pcb]
2020-12-22 Argon - all elements and start paths
    [argon.kicad_pcb, argon.sch]
2020-12-22 Smaller argon
    [argon.kicad_pcb]
2020-12-22 PCB wip
    [argon.kicad_pcb]
2020-12-22 Add 0.8 path for usb
    [argon.kicad_pcb]
2020-12-23 USB design
    [argon.kicad_pcb]
2020-12-23 Bigger logo & move resistors
    [argon.kicad_pcb]
2020-12-23 555 routes
    [argon.kicad_pcb]
2020-12-23 FBs routing
    [argon.kicad_pcb]
2020-12-23 TX & RX leds and A pads
    [argon.kicad_pcb]
2020-12-23 V1.8 & V3.3
    [argon.kicad_pcb]
2020-12-23 Move all up to avoid holes overlapping
    [argon.kicad_pcb]
2020-12-23 EEPROM routing
    [argon.kicad_pcb]
2020-12-23 Ground and paths
    [argon.kicad_pcb]
2020-12-23 Missing paths
    [argon.kicad_pcb]
2020-12-23 All routes
    [argon.kicad_pcb]
2020-12-23 Add capacitor footprint without lines
    [argon.kicad_pcb]
2020-12-23 Final touch
    [argon.kicad_pcb]
2020-12-23 GND on front & fix paths
    [argon.kicad_pcb]
2020-12-23 Move capacitor & add filled zone near USB
    [argon.kicad_pcb]
2020-12-23 Fix connected pins on ftdi
    [argon.kicad_pcb]
2020-12-23 Add labels
    [argon.kicad_pcb]
2020-12-23 Small paths adjustments
    [argon.kicad_pcb]
2020-12-23 Rounded corners
    [argon.kicad_pcb]
2020-12-23 Move everything to make more place for labels
    [argon.kicad_pcb]
2020-12-23 Benzene schematic
    [benzene-16.sch]
2020-12-24 Benzene schematic - final
    [benzene-16.sch]
2020-12-24 Benzene pcb
    [argon.kicad_pcb, benzene-16.kicad_pcb, benzene-16.sch]
2020-12-25 Fix argon clearance & benzen step
    [argon.kicad_pcb, benzene-16.step]
2020-12-25 Fix benzene bug (gnd & 3v3)
    [benzene-16.kicad_pcb]
2020-12-25 Final touches
    [benzene-16.kicad_pcb]
2020-12-25 Remove old benzene design
    [benzene.kicad_pcb, benzene.sch, benzene.step]
2021-01-13 Argon boards
2021-01-24 Benzene 1.0
    [benzene.kicad_pcb, benzene.sch, benzene.step]
2021-01-24 Fix incorrectly designed LEDs
    [argon.kicad_pcb, argon.sch]
2021-01-24 Resize board to 62mm, update logo & add pattern
    [argon.kicad_pcb]
2021-01-24 Argon 1.1
    [argon.kicad_pcb, argon.sch]
2021-11-08 Update README.md
    https://forum.kicad.info/t/warning-avoid-all-links-to-kicad-pcb-org-use-kicad-org/31521
